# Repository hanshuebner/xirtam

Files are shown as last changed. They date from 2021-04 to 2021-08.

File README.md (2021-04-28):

## Synopsis

xirtam is a an interface device to connect a USB keyboard to a computer with a
matrix keyboard interface, i.e. an 8 bit home computer.

The repository contains the AT90USB1287 firmware source code and KiCAD schematic/PCB
design for the xirtam project.  It is a fork of the [SmallyMouse2](https://www.waitingforfriday.com/?p=827)
project that implements a similar device for realy computer mice.

## Motivation

8 bit home computers interface to their keyboard through a matrix style interface.
The main CPU periodically scans the keyboard matrix for key presses converts them to
characters or control information as required.  This is in contrast to more modern
machines, where a separate microcontroller performs the keyboard scanning task and
interfaces to the main CPU using a serial interface.

Being able to use an USB interface with an 8 bit home computer is often desireable
because of the bad quality that home computer keyboards typically have. Some don't
even have physical keys, but most use cheap mechanical switches.  Furthermore, the
keyboard is always integrated into the system unit, and a detachable keyboard is
much desireable.

## Implementation

Interfacing a modern keyboard to a computer with a matrix interface is slightly
tricky because of the way how the scanning is typically implemented.  The keyboard
is organized as a matrix of switches, with each switch connecting a particular pair
of a vertical and horizontal line of the matrix.  It does so by sending a high 
signal to one of the row lines of the matrix, and then reading back the
value sent by the keyboard on the column lines.  For each key pressed in the
particular row, the respective column bit will be high.

The scanning of the keyboard is a rapid process, with little time between when the
row was selected and the column being read.  Typically, there will only be a few
hundred nanoseconds between when the CPU selects a row and when it reads back the
column data.  Hence, software based solutions to emulate a keyboard matrix, while
they exist, require a very fast microcontroller or additional hardware or software
running on the micro to work.

xirtam approaches the timing problem by using a matrix switch chip that works
the same way as a physical keyboard.  The physical switches of the keyboard are
replaced by semiconductor switches inside of the chip which can be controlled
by a host interface.  When one of the switches is turned on by the host, it
connects the row and column at its intersection until the host turns if off again.
Hence, the scanning of the keyboard by the home computer can be done at arbitrary
rate, like with a physical keyboard.

Matrix switch chips are used in video and
audio crossbar applications and have been around for a long time.  They are
available in various configurations and sizes and are reasonably priced.  The
chip chosen for xirtam is the [MT093](https://www.microsemi.com/document-portal/doc_download/127014-mt093-datasheet-sept11).  
It was developed by Zarlink (now Microchip) and provides for 96 switches in an 
8x12 configuration.  It provides an easy to use interface for control, 
allowing the microcontroller to address one of the switches on a parallel address
bus and sending the desired switch state on a separate data bit.

xirtam supports both JTAG and USB bootloader programming.  The AT90USB1287 
is pre-programmed by Atmel with the (FLIP) DFU bootloader; this bootloader is 
recognised by Atmel Studio as a programming device and can be used to flash the 
firmware to the board.

## Installation

Note: This is an Atmel Studio 7 project that can be loaded and compiled by the IDE

Please see http://www.waitingforfriday.com/?p=827 for detailed documentation about SmallyMouse2

## Authors

SmallyMouse2 was written and is maintained by Simon Inns.  It was adapted to xirtam
by Hans Hübner.

## License (Software)

    SmallyMouse2 is free software: you can redistribute it and/or modify
    it under the terms of the GNU General Public License as published by
    the Free Software Foundation, either version 3 of the License, or
    (at your option) any later version.

    SmallyMouse2 is distributed in the hope that it will be useful,
    but WITHOUT ANY WARRANTY; without even the implied warranty of
    MERCHANTABILITY or FITNESS FOR A PARTICULAR PURPOSE.  See the
    GNU General Public License for more details.

    You should have received a copy of the GNU General Public License
    along with SmallyMouse2. If not, see <http://www.gnu.org/licenses/>.

## License (Hardware)

Both the schematic and the PCB design of xirtam (i.e. the KiCAD project and files)
are covered by a Creative Commons license; as with the software you are welcome 
(and encouraged!) to extend, re-spin and otherwise use and modify the design as 
allowed by the license.  However; under the terms of the Attribution-ShareAlike 
4.0 International (CC BY-SA 4.0) license you are required to release your design 
5.(or redesign) under the same license.  For details of the licensing requirements 
6.please see <https://creativecommons.org/licenses/by-sa/4.0/>

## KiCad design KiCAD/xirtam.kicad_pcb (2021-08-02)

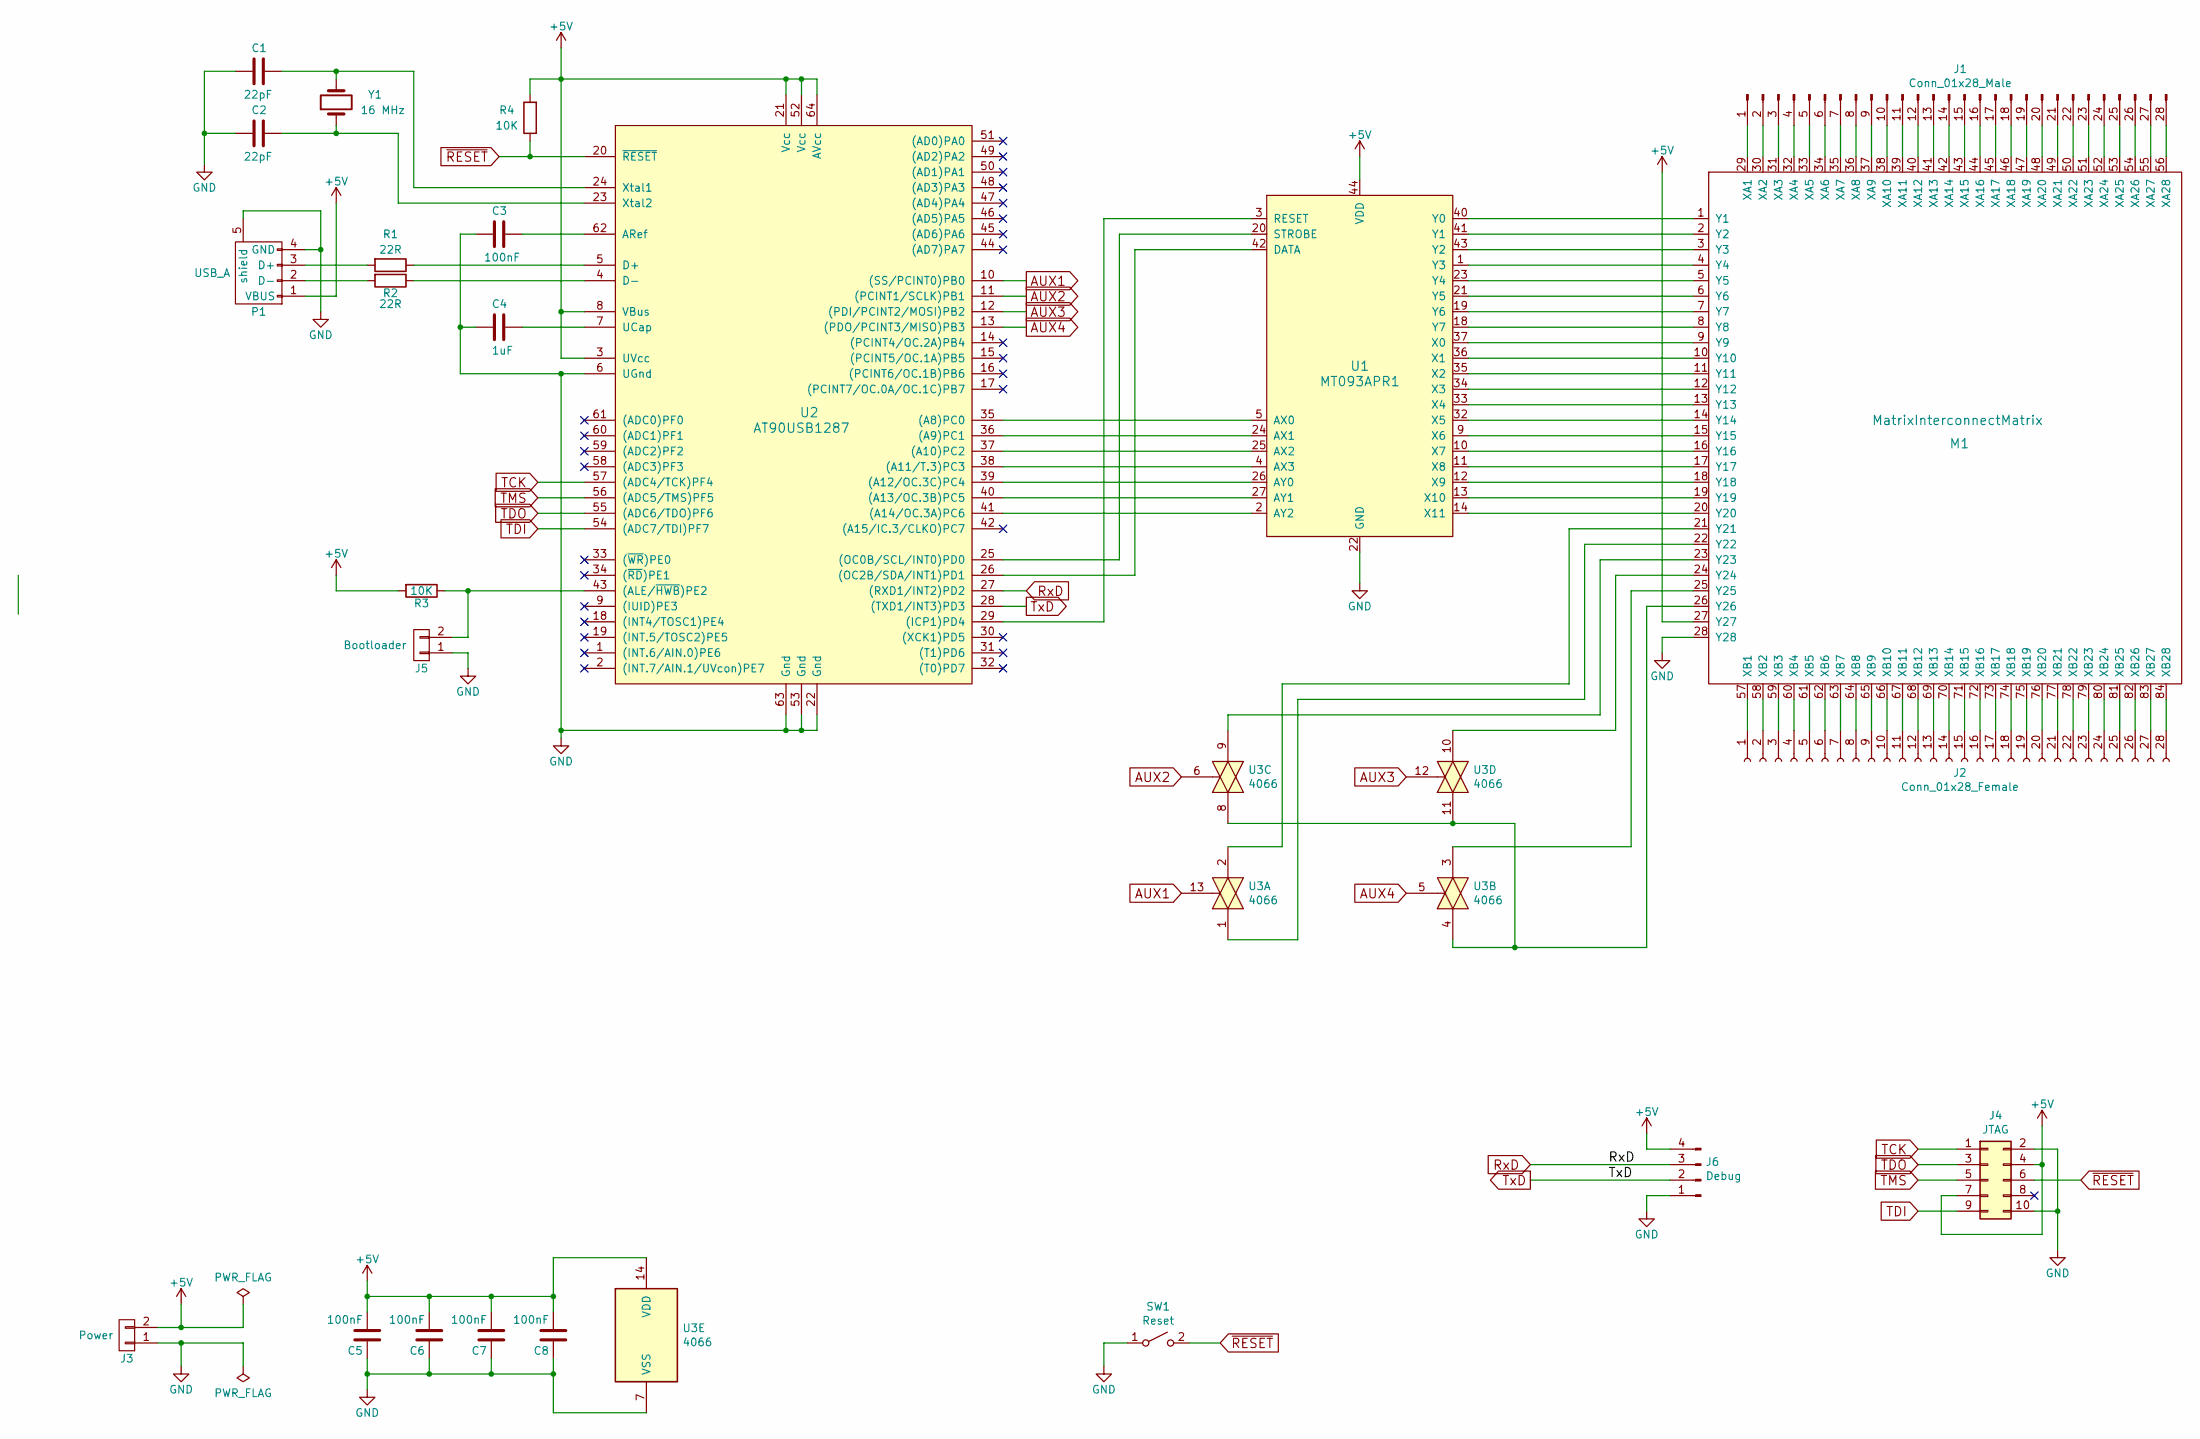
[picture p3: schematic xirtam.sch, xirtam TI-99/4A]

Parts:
C1, C2: 22pF; C_0603_1608Metric_Pad1.05x0.95mm_HandSolder
C3, C5, C6, C7, C8: 100nF; C_0603_1608Metric_Pad1.05x0.95mm_HandSolder
C4: 1uF; C_0603_1608Metric_Pad1.05x0.95mm_HandSolder
J1: Conn_01x28_Male; PinHeader_1x28_P2.54mm_Horizontal
J2: Conn_01x28_Female; PinSocket_1x28_P2.54mm_Horizontal
J3: Power; PinHeader_1x02_P2.54mm_Horizontal
J4: JTAG; IDC-Header_2x05_P2.54mm_Horizontal
J5: Bootloader; PinHeader_1x02_P2.54mm_Horizontal
J6: Debug; PinHeader_1x04_P2.54mm_Horizontal
M1: MatrixInterconnectMatrix; matrixinterconnectmatrix
P1: USB_A; Amphenol_87583-2010BLF
R1, R2: 22R; R_0603_1608Metric_Pad1.05x0.95mm_HandSolder
R3, R4: 10K; R_0603_1608Metric_Pad1.05x0.95mm_HandSolder
SW1: Reset; SW_SPST_FSMSM
U1: MT093APR1; PLCC-44
U2: AT90USB1287; TQFP-64_14x14mm_Pitch0.8mm
U3: 4066; SO-14_5.3x10.2mm_P1.27mm
Y1: 16 MHz; Crystal_SMD_5032-2pin_5.0x3.2mm_HandSoldering

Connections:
+5V: C5.2, C6.2, C7.2, C8.2, J3.2, J4.4, J4.7, J6.4, M1.27 (Y27), P1.1 (VBUS), R3.2, R4.2, U1.44 (VDD), U2.3 (UVcc), U2.8 (VBus), U2.21 (Vcc), U2.52 (Vcc), U2.64 (AVcc), U3.14 (VDD)
AUX1: U2.10 ((SS/PCINT0)PB0), U3.13
AUX2: U2.11 ((PCINT1/SCLK)PB1), U3.6
AUX3: U2.12 ((PDI/PCINT2/MOSI)PB2), U3.12
AUX4: U2.13 ((PDO/PCINT3/MISO)PB3), U3.5
GND: C1.2, C2.2, C3.2, C4.2, C5.1, C6.1, C7.1, C8.1, J3.1, J4.2, J4.10, J5.1, J6.1, M1.28 (Y28), P1.4 (GND), P1.5 (shield), SW1.1 (A), U1.22 (GND), U2.6 (UGnd), U2.22 (Gnd), U2.53 (Gnd), U2.63 (Gnd), U3.7 (VSS)
unnamed: C1.1, U2.24 (Xtal1), Y1.2
unnamed: C2.1, U2.23 (Xtal2), Y1.1
unnamed: C3.1, U2.62 (ARef)
unnamed: C4.1, U2.7 (UCap)
unnamed: J1.1, M1.29 (XA1)
unnamed: J1.2, M1.30 (XA2)
unnamed: J1.3, M1.31 (XA3)
unnamed: J1.4, M1.32 (XA4)
unnamed: J1.5, M1.33 (XA5)
unnamed: J1.6, M1.34 (XA6)
unnamed: J1.7, M1.35 (XA7)
unnamed: J1.8, M1.36 (XA8)
unnamed: J1.9, M1.37 (XA9)
unnamed: J1.10, M1.38 (XA10)
unnamed: J1.11, M1.39 (XA11)
unnamed: J1.12, M1.40 (XA12)
unnamed: J1.13, M1.41 (XA13)
unnamed: J1.14, M1.42 (XA14)
unnamed: J1.15, M1.43 (XA15)
unnamed: J1.16, M1.44 (XA16)
unnamed: J1.17, M1.45 (XA17)
unnamed: J1.18, M1.46 (XA18)
unnamed: J1.19, M1.47 (XA19)
unnamed: J1.20, M1.48 (XA20)
unnamed: J1.21, M1.49 (XA21)
unnamed: J1.22, M1.50 (XA22)
unnamed: J1.23, M1.51 (XA23)
unnamed: J1.24, M1.52 (XA24)
unnamed: J1.25, M1.53 (XA25)
unnamed: J1.26, M1.54 (XA26)
unnamed: J1.27, M1.55 (XA27)
unnamed: J1.28, M1.56 (XA28)
unnamed: J2.1, M1.57 (XB1)
unnamed: J2.2, M1.58 (XB2)
unnamed: J2.3, M1.59 (XB3)
unnamed: J2.4, M1.60 (XB4)
unnamed: J2.5, M1.61 (XB5)
unnamed: J2.6, M1.62 (XB6)
unnamed: J2.7, M1.63 (XB7)
unnamed: J2.8, M1.64 (XB8)
unnamed: J2.9, M1.65 (XB9)
unnamed: J2.10, M1.66 (XB10)
unnamed: J2.11, M1.67 (XB11)
unnamed: J2.12, M1.68 (XB12)
unnamed: J2.13, M1.69 (XB13)
unnamed: J2.14, M1.70 (XB14)
unnamed: J2.15, M1.71 (XB15)
unnamed: J2.16, M1.72 (XB16)
unnamed: J2.17, M1.73 (XB17)
unnamed: J2.18, M1.74 (XB18)
unnamed: J2.19, M1.75 (XB19)
unnamed: J2.20, M1.76 (XB20)
unnamed: J2.21, M1.77 (XB21)
unnamed: J2.22, M1.78 (XB22)
unnamed: J2.23, M1.79 (XB23)
unnamed: J2.24, M1.80 (XB24)
unnamed: J2.25, M1.81 (XB25)
unnamed: J2.26, M1.82 (XB26)
unnamed: J2.27, M1.83 (XB27)
unnamed: J2.28, M1.84 (XB28)
unnamed: J5.2, R3.1, U2.43 ((ALE/~HWB~)PE2)
unnamed: M1.1 (Y1), U1.40 (Y0)
unnamed: M1.2 (Y2), U1.41 (Y1)
unnamed: M1.3 (Y3), U1.43 (Y2)
unnamed: M1.4 (Y4), U1.1 (Y3)
unnamed: M1.5 (Y5), U1.23 (Y4)
unnamed: M1.6 (Y6), U1.21 (Y5)
unnamed: M1.7 (Y7), U1.19 (Y6)
unnamed: M1.8 (Y8), U1.18 (Y7)
unnamed: M1.9 (Y9), U1.37 (X0)
unnamed: M1.10 (Y10), U1.36 (X1)
unnamed: M1.11 (Y11), U1.35 (X2)
unnamed: M1.12 (Y12), U1.34 (X3)
unnamed: M1.13 (Y13), U1.33 (X4)
unnamed: M1.14 (Y14), U1.32 (X5)
unnamed: M1.15 (Y15), U1.9 (X6)
unnamed: M1.16 (Y16), U1.10 (X7)
unnamed: M1.17 (Y17), U1.11 (X8)
unnamed: M1.18 (Y18), U1.12 (X9)
unnamed: M1.19 (Y19), U1.13 (X10)
unnamed: M1.20 (Y20), U1.14 (X11)
unnamed: M1.21 (Y21), U3.2
unnamed: M1.22 (Y22), U3.1
unnamed: M1.23 (Y23), U3.9
unnamed: M1.24 (Y24), U3.10
unnamed: M1.25 (Y25), U3.3
unnamed: M1.26 (Y26), U3.4, U3.8, U3.11
unnamed: P1.2 (D-), R2.2
unnamed: P1.3 (D+), R1.2
unnamed: R1.1, U2.5 (D+)
unnamed: R2.1, U2.4 (D-)
unnamed: U1.2 (AY2), U2.41 ((A14/OC.3A)PC6)
unnamed: U1.3 (RESET), U2.29 ((ICP1)PD4)
unnamed: U1.4 (AX3), U2.38 ((A11/T.3)PC3)
unnamed: U1.5 (AX0), U2.35 ((A8)PC0)
unnamed: U1.20 (STROBE), U2.25 ((OC0B/SCL/INT0)PD0)
unnamed: U1.24 (AX1), U2.36 ((A9)PC1)
unnamed: U1.25 (AX2), U2.37 ((A10)PC2)
unnamed: U1.26 (AY0), U2.39 ((A12/OC.3C)PC4)
unnamed: U1.27 (AY1), U2.40 ((A13/OC.3B)PC5)
unnamed: U1.42 (DATA), U2.26 ((OC2B/SDA/INT1)PD1)
RxD: J6.3, U2.27 ((RXD1/INT2)PD2)
TCK: J4.1, U2.57 ((ADC4/TCK)PF4)
TDI: J4.9, U2.54 ((ADC7/TDI)PF7)
TDO: J4.3, U2.55 ((ADC6/TDO)PF6)
TMS: J4.5, U2.56 ((ADC5/TMS)PF5)
TxD: J6.2, U2.28 ((TXD1/INT3)PD3)
~RESET: J4.6, R4.1, SW1.2 (B), U2.20 (~RESET)

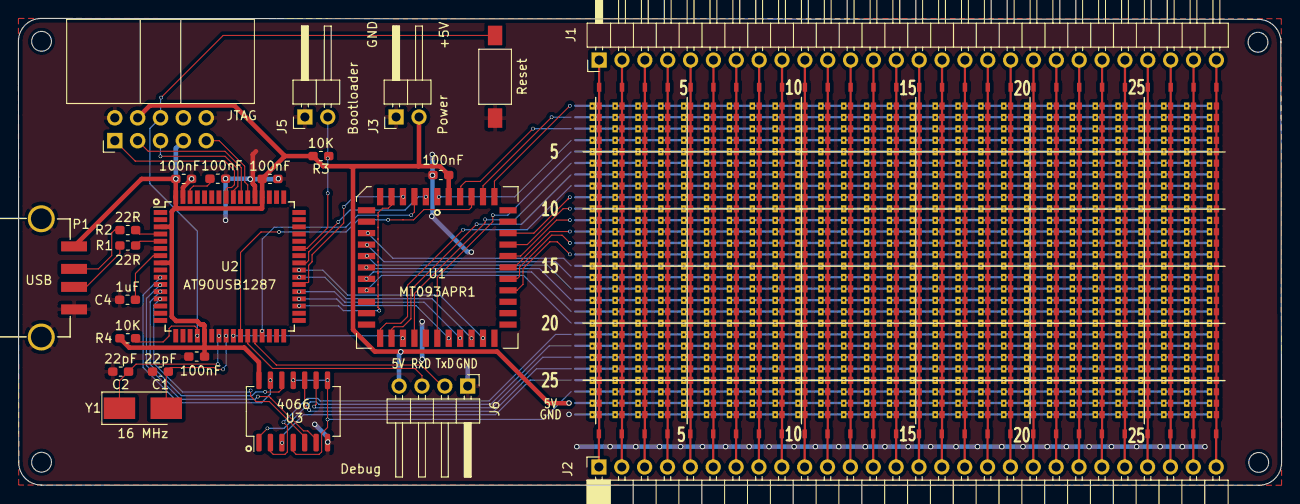
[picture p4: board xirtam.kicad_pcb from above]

Board: 2 copper layers, 140.3 x 51.9 mm, 25 parts (0 on the bottom side), 114 nets.

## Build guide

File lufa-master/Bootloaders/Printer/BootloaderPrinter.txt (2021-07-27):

/** \file
 *
 *  This file contains special DoxyGen information for the generation of the main page and other special
 *  documentation pages. It is not a project source file.
 */

/** \mainpage Printer Class USB AVR Bootloader
 *
 *  \section Sec_Compat Demo Compatibility:
 *
 *  The following list indicates what microcontrollers are compatible with this demo.
 *
 *  \li Series 7 USB AVRs (AT90USBxxx7)
 *  \li Series 6 USB AVRs (AT90USBxxx6)
 *  \li Series 4 USB AVRs (ATMEGAxxU4)
 *  \li Series 2 USB AVRs (AT90USBxx2, ATMEGAxxU2)
 *
 *  \section Sec_Info USB Information:
 *
 *  The following table gives a rundown of the USB utilization of this demo.
 *
 *  <table>
 *   <tr>
 *    <td><b>USB Mode:</b></td>
 *    <td>Device</td>
 *   </tr>
 *   <tr>
 *    <td><b>USB Class:</b></td>
 *    <td>Printer Class</td>
 *   </tr>
 *   <tr>
 *    <td><b>USB Subclass:</b></td>
 *    <td>Printer Subclass</td>
 *   </tr>
 *   <tr>
 *    <td><b>Relevant Standards:</b></td>
 *    <td>USBIF Printer Class Standard</td>
 *   </tr>
 *   <tr>
 *    <td><b>Supported USB Speeds:</b></td>
 *    <td>Full Speed Mode</td>
 *   </tr>
 *  </table>
 *
 *  \section Sec_Description Project Description:
 *
 *  This bootloader enumerates to the host as a Generic Text Only Printer device, capable of reading and parsing
 *  "printed" plain-text Intel HEX files to load firmware onto the AVR.
 *
 *  Out of the box this bootloader builds for the AT90USB1287 with an 8KB bootloader section size, and will fit
 *  into 4KB of bootloader space. If you wish to alter this size and/or change the AVR model, you will need to
 *  edit the MCU, FLASH_SIZE_KB and BOOT_SECTION_SIZE_KB values in the accompanying makefile.
 *
 *  When the bootloader is running, the board's LED(s) will flash at regular intervals to distinguish the
 *  bootloader from the normal user application.
 *
 *  \section Sec_Running Running the Bootloader
 *
 *  On the USB AVR8 devices, setting the \c HWBE device fuse will cause the bootloader to run if the \c HWB pin of
 *  the AVR is grounded when the device is reset.
 *
 *  The are two behaviours of this bootloader, depending on the device's fuses:
 *
 *  <b>If the device's BOOTRST fuse is set</b>, the bootloader will run any time the system is reset from
 *  the external reset pin, unless no valid user application has been loaded. To initiate the bootloader, the
 *  device's external reset pin should be grounded momentarily.
 *
 *  <b>If the device's BOOTRST fuse is not set</b>, the bootloader will run only if initiated via a software
 *  jump, or if the \c HWB pin was low during the last device reset (if the \c HWBE fuse is set).
 *
 *  For board specific exceptions to the above, see below.
 *
 *  \subsection SSec_XPLAIN Atmel Xplain Board
 *  Ground the USB AVR JTAG's \c TCK pin to ground when powering on the board to start the bootloader. This assumes the
 *  \c HWBE fuse is cleared and the \c BOOTRST fuse is set as the HWBE pin is not user accessible on this board.
 *
 *  \subsection SSec_Leonardo Arduino Leonardo Board
 *  Ground \c IO13 when powering the board to start the bootloader. This assumes the \c HWBE fuse is cleared and the
 *  \c BOOTRST fuse is set as the HWBE pin is not user accessible on this board.
 *
 *  \section Sec_Installation Driver Installation
 *
 *  This bootloader uses the Generic Text-Only printer drivers inbuilt into all modern operating systems, thus no
 *  additional drivers need to be supplied for correct operation.
 *
 *  \section Sec_HostApp Host Controller Application
 *
 *  This bootloader is compatible with Notepad under Windows, and the command line \c lpr utility under Linux.
 *
 *  \subsection SSec_Notepad Notepad (Windows)
 *
 *  While most text applications under Windows will be compatible with the bootloader, the inbuilt Notepad utility
 *  is recommended as it will introduce minimal formatting changes to the output stream. To program with Notepad,
 *  open the target HEX file and print it to the Generic Text Only printer device the bootloader creates.
 *
 *  \subsection SSec_LPR LPR (Linux)
 *
 *  While the CUPS framework under Linux will enumerate the bootloader as a Generic Text-Only printer, many
 *  applications will refuse to print to the device due to the lack of rich formatting options available. As a result,
 *  under Linux HEX files must be printed via the low level \c lpr utility instead.
 *
 *  \code
 *  cat Mouse.hex | lpr
 *  \endcode
 *
 *  \section Sec_API User Application API
 *
 *  Several user application functions for FLASH and other special memory area manipulations are exposed by the bootloader,
 *  allowing the user application to call into the bootloader at runtime to read and write FLASH data.
 *
 *  By default, the bootloader API jump table is located 32 bytes from the end of the device's FLASH memory, and follows the
 *  following layout:
 *
 *  \code
 *  #define BOOTLOADER_API_TABLE_SIZE          32
 *  #define BOOTLOADER_API_TABLE_START         ((FLASHEND + 1UL) - BOOTLOADER_API_TABLE_SIZE)
 *  #define BOOTLOADER_API_CALL(Index)         (void*)((BOOTLOADER_API_TABLE_START + (Index * 2)) / 2)
 *
 *  void    (*BootloaderAPI_ErasePage)(uint32_t Address)               = BOOTLOADER_API_CALL(0);
 *  void    (*BootloaderAPI_WritePage)(uint32_t Address)               = BOOTLOADER_API_CALL(1);
 *  void    (*BootloaderAPI_FillWord)(uint32_t Address, uint16_t Word) = BOOTLOADER_API_CALL(2);
 *  uint8_t (*BootloaderAPI_ReadSignature)(uint16_t Address)           = BOOTLOADER_API_CALL(3);
 *  uint8_t (*BootloaderAPI_ReadFuse)(uint16_t Address)                = BOOTLOADER_API_CALL(4);
 *  uint8_t (*BootloaderAPI_ReadLock)(void)                            = BOOTLOADER_API_CALL(5);
 *  void    (*BootloaderAPI_WriteLock)(uint8_t LockBits)               = BOOTLOADER_API_CALL(6);
 *
 *  #define BOOTLOADER_MAGIC_SIGNATURE_START   (BOOTLOADER_API_TABLE_START + (BOOTLOADER_API_TABLE_SIZE - 2))
 *  #define BOOTLOADER_MAGIC_SIGNATURE         0xDCFB
 *
 *  #define BOOTLOADER_CLASS_SIGNATURE_START   (BOOTLOADER_API_TABLE_START + (BOOTLOADER_API_TABLE_SIZE - 4))
 *  #define BOOTLOADER_PRINTER_SIGNATURE       0xDF20
 *
 *  #define BOOTLOADER_ADDRESS_START           (BOOTLOADER_API_TABLE_START + (BOOTLOADER_API_TABLE_SIZE - 8))
 *  #define BOOTLOADER_ADDRESS_LENGTH          4
 *  \endcode
 *
 *  From the application the API support of the bootloader can be detected by reading the FLASH memory bytes located at address
 *  \c BOOTLOADER_MAGIC_SIGNATURE_START and comparing them to the value \c BOOTLOADER_MAGIC_SIGNATURE. The class of bootloader
 *  can be determined by reading the FLASH memory bytes located at address \c BOOTLOADER_CLASS_SIGNATURE_START and comparing them
 *  to the value \c BOOTLOADER_PRINTER_SIGNATURE. The start address of the bootloader can be retrieved by reading the bytes of FLASH
 *  memory starting from address \c BOOTLOADER_ADDRESS_START.
 *
 *  \subsection SSec_API_MemLayout Device Memory Map
 *  The following illustration indicates the final memory map of the device when loaded with the bootloader.
 *
 *  \verbatim
 *  +----------------------------+ 0x0000
 *  |                            |
 *  |                            |
 *  |                            |
 *  |                            |
 *  |                            |
 *  |                            |
 *  |                            |
 *  |                            |
 *  |      User Application      |
 *  |                            |
 *  |                            |
 *  |                            |
 *  |                            |
 *  |                            |
 *  |                            |
 *  |                            |
 *  +----------------------------+ FLASHEND - BOOT_SECTION_SIZE
 *  |                            |
 *  |   Bootloader Application   |
 *  | (Not User App. Accessible) |
 *  |                            |
 *  +----------------------------+ FLASHEND - 96
 *  |   API Table Trampolines    |
 *  | (Not User App. Accessible) |
 *  +----------------------------+ FLASHEND - 32
 *  |    Bootloader API Table    |
 *  |   (User App. Accessible)   |
 *  +----------------------------+ FLASHEND - 8
 *  |   Bootloader ID Constants  |
 *  |   (User App. Accessible)   |
 *  +----------------------------+ FLASHEND
 *  \endverbatim
 *
 *
 *  \section Sec_KnownIssues Known Issues:
 *
 *  \par On Linux machines, new firmware fails to be sent to the device via CUPS.
 *  Only a limited subset of normal printer functionality is exposed via the
 *  bootloader, causing CUPS to reject print requests from applications that
 *  are unable to handle true plain-text printing. For best results, the low
 *  level \c lpr command should be used to print new firmware to the bootloader.
 *
 *  \section Sec_Options Project Options
 *
 *  The following defines can be found in this demo, which can control the demo behaviour when defined, or changed in value.
 *
 *  <table>
 *   <tr>
 *    <td>
 *     None
 *    </td>
 *   </tr>
 *  </table>
 */

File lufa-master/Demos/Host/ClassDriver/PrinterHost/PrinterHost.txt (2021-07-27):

/** \file
 *
 *  This file contains special DoxyGen information for the generation of the main page and other special
 *  documentation pages. It is not a project source file.
 */

/** \mainpage Printer Host Demo
 *
 *  \section Sec_Compat Demo Compatibility:
 *
 *  The following list indicates what microcontrollers are compatible with this demo.
 *
 *  \li Series 7 USB AVRs (AT90USBxxx7)
 *
 *  \section Sec_Info USB Information:
 *
 *  The following table gives a rundown of the USB utilization of this demo.
 *
 *  <table>
 *   <tr>
 *    <td><b>USB Mode:</b></td>
 *    <td>Host</td>
 *   </tr>
 *   <tr>
 *    <td><b>USB Class:</b></td>
 *    <td>Printer Device</td>
 *   </tr>
 *   <tr>
 *    <td><b>USB Subclass:</b></td>
 *    <td>Bidirectional Protocol</td>
 *   </tr>
 *   <tr>
 *    <td><b>Relevant Standards:</b></td>
 *    <td>USBIF Printer Class Specification \n
 *        PCL Language Specification</td>
 *   </tr>
 *   <tr>
 *    <td><b>Supported USB Speeds:</b></td>
 *    <td>Low Speed Mode \n
 *        Full Speed Mode</td>
 *   </tr>
 *  </table>
 *
 *  \section Sec_Description Project Description:
 *
 *  Printer host demonstration application. This gives a simple reference
 *  application for implementing a USB Printer host, for USB printers using
 *  the bidirectional data encapsulation protocol and PCL language.
 *
 *  Upon connection of a compatible printer, the printer's device ID is sent
 *  to the AVR's serial port, and a simple test page is printed using the PCL
 *  printer language.
 *
 *  \section Sec_Options Project Options
 *
 *  The following defines can be found in this demo, which can control the demo behaviour when defined, or changed in value.
 *
 *  <table>
 *   <tr>
 *    <td>
 *     None
 *    </td>
 *   </tr>
 *  </table>
 */

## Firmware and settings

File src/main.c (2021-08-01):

/************************************************************************
	main.c

	Main functions
    xirtam - USB keyboard to switch matrix converter
    Copyright (C) 2017-2020 Simon Inns
    Copyright (C) 2021 Hans Hübner

	This file is part of xirtam.

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
	Email: hans.huebner@gmail.com

************************************************************************/

// Important notice:  If you port this firmware to another hardware design
// it *will be* a derivative of the original and therefore you must pay attention
// to the CC hardware licensing and release your hardware design as per the share-
// alike license.  Keep it open! ...and yes, that includes you Commodore chaps.

// System includes
#include <avr/io.h>
#include <avr/wdt.h>
#include <avr/pgmspace.h>
#include <avr/interrupt.h>
#include <avr/power.h>
#include <stdio.h>
#include <stdlib.h>

#include <util/delay.h>

// Note: xirtam makes extensive use of the LUFA libraries:
//
// LUFA Library
// Copyright (C) Dean Camera, 2015.
// dean [at] fourwalledcubicle [dot] com
// www.lufa-lib.org

// Include LUFA libraries
#include <LUFA/Drivers/Misc/TerminalCodes.h>
#include <LUFA/Drivers/USB/USB.h>
#include <LUFA/Drivers/Peripheral/Serial.h>
#include <LUFA/Platform/Platform.h>

#include "usb_hid_keys.h"
#include "bit_array.h"

// USB configuration

/** HID Report Descriptor Usage Page value for a desktop keyboard. */
#define USAGE_PAGE_KEYBOARD      0x07

USB_ClassInfo_HID_Host_t Keyboard_HID_Interface =
  {
   .Config = {
              .DataINPipe = {
                             .Address = (PIPE_DIR_IN  | 1),
                             .Banks = 1,
                             },
              .DataOUTPipe = {
                              .Address        = (PIPE_DIR_OUT | 2),
                              .Banks          = 1,
                              },
              .HIDInterfaceProtocol = HID_CSCP_KeyboardBootProtocol
              },
  };


// MT093 hardware interface

#define BIT_STROBE 0x01
#define BIT_DATA   0x02
#define BIT_TXD    0x08
#define BIT_RESET  0x10

// Matrix definition

#define MATRIX_ROWS 7
#define MATRIX_COLUMNS 8

#define MATRIX_COUNT (MATRIX_ROWS * MATRIX_COLUMNS)

// Mapping from USB HID keyboard codes to matrix addresses

typedef struct {
  uint8_t row;
  uint8_t column;
} matrix_address_t;

#define MATRIX(r, c) { .row = r, .column = c }

typedef struct {
  uint8_t input_code;
  matrix_address_t matrix_address1, matrix_address2;
} key_map_t;

#define MAP(code, row, column) { code, MATRIX(row, column), MATRIX(row, column) }
#define MAP2(code, row1, column1, row2, column2) { code, MATRIX(row1, column1), MATRIX(row2, column2) }

#define LAST_MAP_ENTRY { .input_code = 0 }

key_map_t modifier_map[] =
  {
   MAP(KEY_MOD_LCTRL, 3, 6),
   MAP(KEY_MOD_LSHIFT, 3, 2),
   MAP(KEY_MOD_LALT, 3, 5),
   MAP(KEY_MOD_RCTRL, 3, 6),
   MAP(KEY_MOD_RSHIFT, 3, 2),
   MAP(KEY_MOD_RALT, 3, 5),
   LAST_MAP_ENTRY
  };

key_map_t key_map[] =
  {
   MAP(KEY_A, 1, 2),
   MAP(KEY_B, 2, 7),
   MAP(KEY_C, 5, 7),
   MAP(KEY_D, 5, 2),
   MAP(KEY_E, 5, 6),
   MAP(KEY_F, 6, 2),
   MAP(KEY_G, 2, 2),
   MAP(KEY_H, 2, 3),
   MAP(KEY_I, 5, 0),
   MAP(KEY_J, 6, 3),
   MAP(KEY_K, 5, 3),
   MAP(KEY_L, 4, 3),
   MAP(KEY_M, 6, 4),
   MAP(KEY_N, 2, 4),
   MAP(KEY_O, 4, 0),
   MAP(KEY_P, 1, 0),
   MAP(KEY_Q, 1, 6),
   MAP(KEY_R, 6, 6),
   MAP(KEY_S, 4, 2),
   MAP(KEY_T, 2, 6),
   MAP(KEY_U, 6, 0),
   MAP(KEY_V, 6, 7),
   MAP(KEY_W, 4, 6),
   MAP(KEY_X, 4, 7),
   MAP(KEY_Y, 2, 0),
   MAP(KEY_Z, 1, 7),
   MAP(KEY_0, 1, 1),
   MAP(KEY_1, 1, 5),
   MAP(KEY_2, 4, 5),
   MAP(KEY_3, 5, 5),
   MAP(KEY_4, 6, 5),
   MAP(KEY_5, 2, 5),
   MAP(KEY_6, 2, 1),
   MAP(KEY_7, 6, 1),
   MAP(KEY_8, 5, 1),
   MAP(KEY_9, 4, 1),
   MAP(KEY_ENTER, 3, 0),
   MAP(KEY_KPENTER, 3, 0),
   MAP(KEY_EQUAL, 3, 4),
   MAP(KEY_SPACE, 3, 3),
   MAP(KEY_DOT, 4, 4),
   MAP(KEY_COMMA, 5, 4),
   MAP(KEY_SEMICOLON, 1, 3),
   MAP(KEY_SLASH, 1, 4),
   MAP2(KEY_LEFT, 3, 7, 4, 2),
   MAP2(KEY_BACKSPACE, 3, 7, 4, 2),
   MAP2(KEY_RIGHT, 3, 7, 5, 2),
   MAP2(KEY_UP, 3, 7, 5, 6),
   MAP2(KEY_DOWN, 3, 7, 4, 7),
   MAP2(KEY_BACKSLASH, 3, 7, 1, 7),
   MAP2(KEY_GRAVE, 3, 7, 5, 7),
   MAP2(KEY_LEFTBRACE, 3, 7, 6, 6),
   MAP2(KEY_RIGHTBRACE, 3, 7, 2, 6),
   MAP2(KEY_MINUS, 3, 7, 6, 0),
   MAP2(KEY_APOSTROPHE, 3, 7, 4, 0),
   MAP2(KEY_PAUSE, 3, 7, 3, 4),
   MAP2(KEY_F1, 3, 7, 1, 5),
   MAP2(KEY_F2, 3, 7, 4, 5),
   MAP2(KEY_F3, 3, 7, 5, 5),
   MAP2(KEY_F4, 3, 7, 6, 5),
   MAP2(KEY_F5, 3, 7, 2, 5),
   MAP2(KEY_F6, 3, 7, 2, 1),
   MAP2(KEY_F7, 3, 7, 6, 1),
   MAP2(KEY_F8, 3, 7, 5, 1),
   MAP2(KEY_F9, 3, 7, 4, 1),
   MAP2(KEY_F10, 3, 7, 1, 1),
   LAST_MAP_ENTRY
  };

key_map_t shift_key_map[] =
  {
   MAP2(KEY_BACKSLASH, 3, 7, 1, 2),
   MAP2(KEY_GRAVE, 3, 7, 4, 6),
   MAP2(KEY_LEFTBRACE, 3, 7, 6, 2),
   MAP2(KEY_RIGHTBRACE, 3, 7, 2, 2),
   MAP2(KEY_SLASH, 3, 7, 5, 0),
   MAP2(KEY_APOSTROPHE, 3, 7, 1, 0),
   MAP2(KEY_MINUS, 3, 2, 3, 4),
   LAST_MAP_ENTRY
  };

void
set_bit(BIT_ARRAY* bits, uint8_t row, uint8_t column) {
  bit_array_set(bits, row * MATRIX_COLUMNS + column);
}

key_map_t*
find_in_map(uint8_t input_code, key_map_t map[]) {
  for (int i = 0; map[i].input_code; i++) {
    if (map[i].input_code == input_code) {
      return &(map[i]);
    }
  }
  return 0;
}

void
map_code(BIT_ARRAY* bits, uint8_t code, key_map_t map[])
{
  key_map_t* map_entry = find_in_map(code, map);
  if (map_entry) {
    set_bit(bits, map_entry->matrix_address1.row, map_entry->matrix_address1.column);
    set_bit(bits, map_entry->matrix_address2.row, map_entry->matrix_address2.column);
  }
}

void
map_modifiers(BIT_ARRAY* bits, uint8_t modifier_mask)
{
  for (uint8_t i = 0; i < 8; i++) {
    uint8_t code = 1 << i;
    if (modifier_mask & code) {
      map_code(bits, code, modifier_map);
    }
  }
}

void
map_key(BIT_ARRAY* bits, uint8_t code, key_map_t map[]) {
  if (code > 1) {
    map_code(bits, code, map);
  }
}

// Initialise the hardware
void initialiseHardware(void)
{
  // Disable the watchdog timer (if set in fuses)
  MCUSR &= ~(1 << WDRF);
  wdt_disable();

  // Disable the clock divider (if set in fuses)
  clock_prescale_set(clock_div_1);

  // Define the output pins
  DDRC |= 0x7F; // Matrix address
  DDRD |= BIT_STROBE | BIT_DATA | BIT_TXD | BIT_RESET;

  // Reset the MT093 chip
  PORTD |= BIT_RESET;
  PORTD &= ~BIT_RESET;

  // Initialise the LUFA USB stack
  USB_Init();

  // By default, xirtam will output USB debug events on the
  // AVR's UART port.  You can monitor the debug console by
  // connecting a serial to USB adapter.  Only the Tx (D3 and 0V
  // pins are required).

  // Initialise the serial UART - 9600 baud 8N1
  Serial_Init(9600, false);

  // Create a serial debug stream on stdio
  Serial_CreateStream(NULL);

  // Output some debug header information to the serial console
  puts_P(PSTR(ESC_FG_YELLOW "xirtam V0.1 - Serial debug console\r\n" ESC_FG_WHITE));
  puts_P(PSTR(ESC_FG_YELLOW "(c)2021 Hans Huebner\r\n" ESC_FG_WHITE));
}

void
matrix_set(uint8_t row, uint8_t column, uint8_t value) {
  printf_P(PSTR("%d/%d => %d\r\n"), row, column, value);

  PORTC = (row << 4) | column;
  if (value) {
    PORTD |= BIT_DATA;
  } else {
    PORTD &= ~BIT_DATA;
  }
  PORTD |= BIT_STROBE;
  PORTD &= ~BIT_STROBE;

  // Reset output ports for easier debugging
  PORTD &= ~BIT_DATA;
  PORTC = 0;
}

void
processReport(USB_KeyboardReport_Data_t* keyboard_report, BIT_ARRAY* old_state) {
  BIT_ARRAY* new_state = bit_array_create(MATRIX_COUNT);
  bit_array_clear_all(new_state);
  bit_index_t next_bit_set = 0;

  // First attempt to map shifted keys - If one of those is found, we
  // don't consult the other maps.
  if (keyboard_report->Modifier & (KEY_MOD_LSHIFT | KEY_MOD_RSHIFT)) {
    for (int i = 0; i < 6; i++) {
      map_key(new_state, keyboard_report->KeyCode[i], shift_key_map);
    }
  }
  if (bit_array_num_bits_set(new_state) == 0) {
    map_modifiers(new_state, keyboard_report->Modifier);
    for (int i = 0; i < 6; i++) {
      map_key(new_state, keyboard_report->KeyCode[i], key_map);
    }
  }

  bit_array_or(old_state, old_state, new_state);

  while (bit_array_find_next_set_bit(old_state, next_bit_set, &next_bit_set)) {
    uint8_t row = next_bit_set / MATRIX_COLUMNS;
    uint8_t column = next_bit_set % MATRIX_COLUMNS;
    matrix_set(row, column, bit_array_get_bit(new_state, next_bit_set));
    if (++next_bit_set == MATRIX_COUNT) {
      break;
    }
  }

  bit_array_copy_all(old_state, new_state);

  bit_array_free(new_state);
}

// Read the keyboard USB report and process the information
void processKeyboard(BIT_ARRAY* old_state)
{
  if ((USB_HostState == HOST_STATE_Configured)
      && HID_Host_IsReportReceived(&Keyboard_HID_Interface)) {

    USB_KeyboardReport_Data_t keyboard_report;
    HID_Host_ReceiveReport(&Keyboard_HID_Interface, &keyboard_report);

    printf_P(PSTR("Mod 0x%02x Keys 0x%02x 0x%02x 0x%02x 0x%02x 0x%02x 0x%02x\r\n"),
             keyboard_report.Modifier,
             keyboard_report.KeyCode[0], keyboard_report.KeyCode[1], keyboard_report.KeyCode[2],
             keyboard_report.KeyCode[3], keyboard_report.KeyCode[4], keyboard_report.KeyCode[5]);

    processReport(&keyboard_report, old_state);
  }
}

// LUFA event handlers ------------------------------------------------------------------------------------------------

// Event handler for the USB_DeviceAttached event. This indicates that a device has been attached to the host, and
// starts the library USB task to begin the enumeration and USB management process.
void EVENT_USB_Host_DeviceAttached(void)
{
  puts_P(PSTR(ESC_FG_GREEN "USB Device attached\r\n" ESC_FG_WHITE));
}

// Event handler for the USB_DeviceUnattached event. This indicates that a device has been removed from the host, and
// stops the library USB task management process.
void EVENT_USB_Host_DeviceUnattached(void)
{
  puts_P(PSTR(ESC_FG_GREEN "USB Device detached\r\n" ESC_FG_WHITE));
}

// Event handler for the USB_DeviceEnumerationComplete event. This indicates that a device has been successfully
// enumerated by the host and is now ready to be used by the application.
void
EVENT_USB_Host_DeviceEnumerationComplete(void)
{
  uint16_t ConfigDescriptorSize;
  uint8_t  ConfigDescriptorData[512];

  if (USB_Host_GetDeviceConfigDescriptor(1, &ConfigDescriptorSize, ConfigDescriptorData,
                                         sizeof(ConfigDescriptorData)) != HOST_GETCONFIG_Successful) {
    puts_P(PSTR("Error Retrieving Configuration Descriptor.\r\n"));
    return;
  }

  if (HID_Host_ConfigurePipes(&Keyboard_HID_Interface,
                              ConfigDescriptorSize, ConfigDescriptorData) != HID_ENUMERROR_NoError) {
    puts_P(PSTR("Attached Device Not a Valid Keyboard.\r\n"));
    return;
  }

  if (USB_Host_SetDeviceConfiguration(1) != HOST_SENDCONTROL_Successful) {
    puts_P(PSTR("Error Setting Device Configuration.\r\n"));
    return;
  }

  if (HID_Host_SetBootProtocol(&Keyboard_HID_Interface) != 0) {
    puts_P(PSTR("Could not Set Boot Protocol Mode.\r\n"));
    USB_Host_SetDeviceConfiguration(0);
    return;
  }

  puts_P(PSTR("Keyboard successfully.\r\n"));
}

// Event handler for the USB_HostError event. This indicates that a hardware error occurred while in host mode.
void
EVENT_USB_Host_HostError(const uint8_t ErrorCode)
{
  USB_Disable();

  printf_P(PSTR(ESC_FG_RED "Host Mode Error!\r\n"
                " -- Error Code %d\r\n" ESC_FG_WHITE), ErrorCode);

  while(1);
}

// Event handler for the USB_DeviceEnumerationFailed event. This indicates that a problem occurred while
// enumerating an attached USB device.
void
EVENT_USB_Host_DeviceEnumerationFailed(const uint8_t ErrorCode,
                                            const uint8_t SubErrorCode)
{
  printf_P(PSTR(ESC_FG_RED "Device Enumeration Error!\r\n"
                " -- Error Code %d\r\n"
                " -- Sub Error Code %d\r\n"
                " -- In State %d\r\n" ESC_FG_WHITE), ErrorCode, SubErrorCode, USB_HostState);
}

bool
CALLBACK_HIDParser_FilterHIDReportItem(HID_ReportItem_t* const CurrentItem)
{
	/* Check the attributes of the current item - see if we are interested in it or not;
	 * only store KEYBOARD usage page items into the Processed HID Report structure to
	 * save RAM and ignore the rest
	 */
	return (CurrentItem->Attributes.Usage.Page == USAGE_PAGE_KEYBOARD);
}

// Main function
int
main(void)
{
  BIT_ARRAY* keyboard_state = bit_array_create(MATRIX_COUNT);

  bit_array_clear_all(keyboard_state);

  // Initialise the hardware
  initialiseHardware();

  // Enable interrupts (required for USB support)
  sei();

  // Main processing loop
  while(1) {
    // Perform any pending keyboard actions
    processKeyboard(keyboard_state);

    // Process the USB host interface
    USB_USBTask();
  }
}

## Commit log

2021-05-13 Complete layout
    [SmallyMouse2.kicad_pcb, xirtam-2021-04-30-07-36-17.sch, xirtam.kicad_pcb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]
2021-05-14 Fix typo
    [xirtam.kicad_pcb, xirtam.sch]
2021-05-14 Remove SmallyMouse2 products
    [SmallyMouse2-B.Cu.gbl, SmallyMouse2-B.Mask.gbs, SmallyMouse2-B.SilkS.gbo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]
2021-07-27 Add LUFA as of today
    [BoardDeviceMap.cfg, BootloaderDeviceMap.cfg]
2021-07-27 Switch to HID keyboard reading, remove mouse code
2021-07-27 Add keyboard matrix diagram Excel sheet
    [ti-99-matrix.xlsx]
2021-07-28 Add in-line connector layout to PCB, no routing
    [xirtam.kicad_pcb, xirtam.sch]
2021-07-29 Add serial port, fix bugs, make SmallyMouse2 compatible
    [xirtam.sch]
2021-07-29 Use LUFA's HID host driver
2021-07-30 Excel tweaks
    [ti-99-matrix.xlsx]
2021-07-31 New PCB layout
    [xirtam.kicad_pcb, xirtam.sch]
2021-08-01 Fix incorrect mapping for left arrow/backspace
    [main.c]
2021-08-02 New layout, updated schematic
    [xirtam.kicad_pcb, xirtam.sch]
2021-08-02 Fix formatting for printing
    [ti-99-matrix.xlsx]

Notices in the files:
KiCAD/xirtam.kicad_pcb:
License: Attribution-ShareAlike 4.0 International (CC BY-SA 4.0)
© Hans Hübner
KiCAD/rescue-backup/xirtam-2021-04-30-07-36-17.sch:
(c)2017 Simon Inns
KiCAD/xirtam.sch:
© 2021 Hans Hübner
